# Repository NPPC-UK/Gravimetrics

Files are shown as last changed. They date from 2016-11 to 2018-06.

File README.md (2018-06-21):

# What is a Gravimetrics phenotyping system?

This system is designed to enable the study of mass/weight change over time for a set or sets of plants. Additionally, the automatic watering and drought of plants are handled by this system.

By recording changes in weight at a minute-minute scale, plant behaviours can be accurately described, allowing for sophisticated and informative research to be undertaken.

Here, a full blueprint and implementation compendium for a plant phenotyping system is provided.

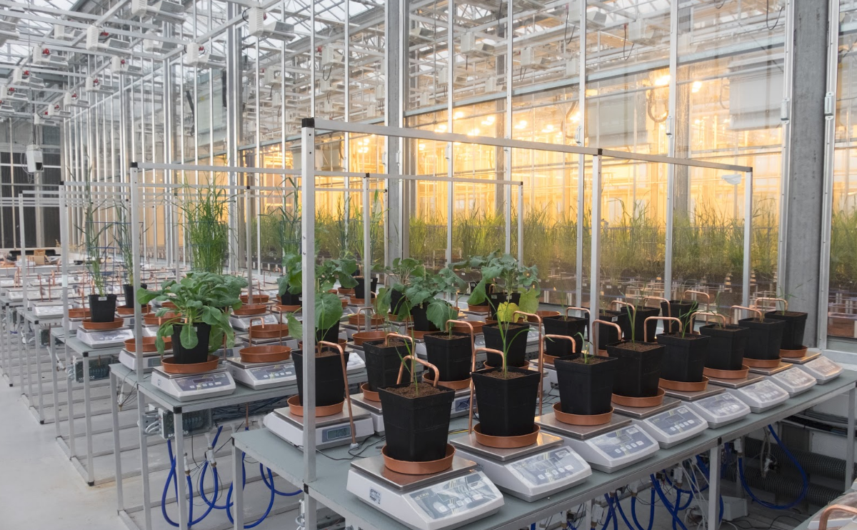
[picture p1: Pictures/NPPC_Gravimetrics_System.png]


# What is provided?

While there exists commercial solutions to gravimetric plant phenotyping, none are provided as open-source solutions.

This project was designed and implemented at the National Plant Phenomics Centre in Aberystwyth, Wales, UK. Built from the ground up using widely available parts, allowing for adaption and scaling.

Designs for physical hardware components used, software for hardware interaction, databases and web interfaces are all provided.

# System Flow Diagram

The basic day-to-day flow is as such:

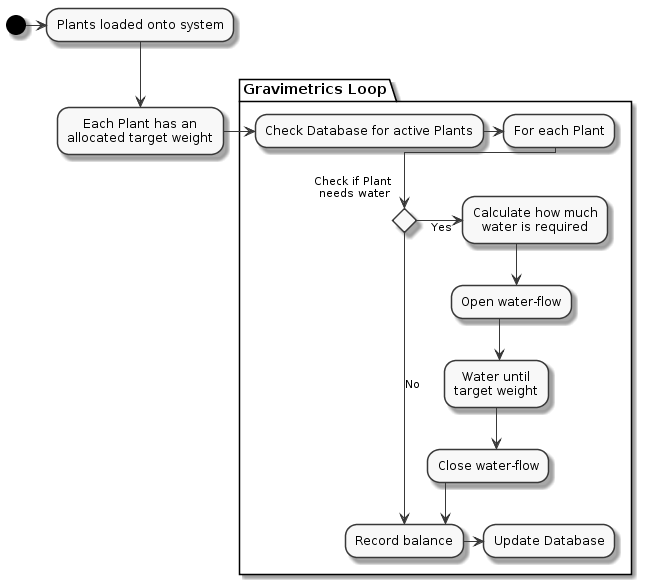
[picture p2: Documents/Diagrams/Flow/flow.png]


Additional interactions, such as updating weights or changing watering times/frequency is performed manually through the web interface.

# Components

Key components provided are:

## Master Controller

To provide a clean and simple interface between hardware and software, a central python script is used to fetch information from the database and pass it to the low-level hardware interactions, it also interprets output and updates the database accordingly.

## Hardware Interaction

A low-level unix C library named "Gravi<sub>Utils</sub>" is used to interact with load-cells (balances) over a serial connection to a Raspberry Pi controller.

In addition to reading balance information for a series of load-cells, the utilities library controls and manages the watering of plants.

## Web Interface

A Flask based web server allows for simple uploading of new plants and experiments onto the system - this is designed for non-technical users to interact with.

Relying heavily on interpreting CSV files and converting them to database queries, the interaction is straight forward.

## System Design Documentation

Everything from electrical wiring diagrams, Raspberry Pi GPIO connections to prototype designs are available in various files.

## Database Configuration

A MySQL database has been used for this project, setup scripts and database schemas are provided that quickly construct and setup all tables and requirements.

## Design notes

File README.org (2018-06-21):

#+TITLE: Gravimetrics - An open source, scalable, plant phenotyping solution
#+AUTHOR: Nathan Hughes, Colin Sauze, Jason Brook, John Doonan
#+OPTIONS: toc:nil

* What is a Gravimetrics phenotyping system?

This system is designed to enable the study of mass/weight change over time for a set or sets of plants. Additionally, the automatic watering and drought of plants are handled by this system.

By recording changes in weight at a minute-minute scale, plant behaviours can be accurately described, allowing for sophisticated and informative research to be undertaken.

Here, a full blueprint and implementation compendium for a plant phenotyping system is provided.



* What is provided?

While there exists commercial solutions to gravimetric plant phenotyping, none are provided as open-source solutions.

This project was designed and implemented at the National Plant Phenomics Centre in Aberystwyth, Wales, UK. Built from the ground up using widely available parts, allowing for adaption and scaling.

Designs for physical hardware components used, software for hardware interaction, databases and web interfaces are all provided.

* System Flow Diagram

The basic day-to-day flow is as such:



Additional interactions, such as updating weights or changing watering times/frequency is performed manually through the web interface.

* Components

Key components provided are:

** Master Controller

To provide a clean and simple interface between hardware and software, a central python script is used to fetch information from the database and pass it to the low-level hardware interactions, it also interprets output and updates the database accordingly.

** Hardware Interaction

A low-level unix C library named "Gravi_Utils" is used to interact with load-cells (balances) over a serial connection to a Raspberry Pi controller.

In addition to reading balance information for a series of load-cells, the utilities library controls and manages the watering of plants.

** Web Interface

A Flask based web server allows for simple uploading of new plants and experiments onto the system - this is designed for non-technical users to interact with.

Relying heavily on interpreting CSV files and converting them to database queries, the interaction is straight forward.

** System Design Documentation

Everything from electrical wiring diagrams, Raspberry Pi GPIO connections to prototype designs are available in various files.

** Database Configuration

A MySQL database has been used for this project, setup scripts and database schemas are provided that quickly construct and setup all tables and requirements.

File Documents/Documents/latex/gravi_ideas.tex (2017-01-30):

% Created 2016-08-02 Tue 10:54
\documentclass[11pt]{article}
\usepackage[utf8]{inputenc}
\usepackage[T1]{fontenc}
\usepackage{fixltx2e}
\usepackage{graphicx}
\usepackage{longtable}
\usepackage{float}
\usepackage{wrapfig}
\usepackage{rotating}
\usepackage[normalem]{ulem}
\usepackage{amsmath}
\usepackage{textcomp}
\usepackage{marvosym}
\usepackage{wasysym}
\usepackage{amssymb}
\usepackage{hyperref}
\tolerance=1000
\author{Nathan}
\date{\today}
\title{gravi\_ideas}
\hypersetup{
  pdfkeywords={},
  pdfsubject={},
  pdfcreator={Emacs 25.1.50.2 (Org mode 8.2.10)}}
\begin{document}

\maketitle
\tableofcontents

\clearpage 

\section{Lifting mechanisms}
\label{sec-1}

One possible solution to our problems could be to introduce a lifting mechanism this would allow us to tare each load cell before a reading, making it 
more likely that we would received a correct reading. 

Any solution which uses a lift would require us to have a dual table system: 

\subsection{Linear Actuator}
\label{sec-1-1}

\href{http://www.instructables.com/id/Electric-Height-Adjustable-Desk/?ALLSTEPS}{Drawing inspiration from this example} we could attempt to make use of the hollow legs in the current
tables by inserting actuators in them. 

Whilst this would make for a nice setup that could be automated, it does become a little more complex 
and does introduce a few areas of concern. However these devices are generally very reliable. 
\begin{figure}[htb]
\centering

\caption{\label{fig:Linear-Actuator}Linear actuators at four corners to lift bench}
\end{figure}

\subsubsection{Alternate design}
\label{sec-1-1-1}

Rather than lifting the plants each time, it might be more prudent to lift the scales themselves rather than the 
plants each time. It would generally be less load on the actuators, however 
\begin{figure}[htb]
\centering

\caption{\label{fig:Linear-Actuator}Linear actuators at four corners to lift bench}
\end{figure}

\subsubsection{Choice of Actuator}
\label{sec-1-1-2}

If we assume that each bench will have up-to 8 load cells on it, each with a max of 10kg each (including itself) 
then we would need a device capable of 80kg force

\begin{center}
\begin{tabular}{rlll}
Option & Price & Potential Lift & Range\\
1 & £89.77 & 28.1N & 48mm\\
2 & £25.55 & 43N & 10mm\\
3 & £174.27 & 500N & 50mm\\
\end{tabular}
\end{center}

I would have assumed that option 2 could have a lot of potential as we really only need a minimum lift 
from the surface of the load cells in order to perform a tare function. 

I've selected option 1 as a mid-priced option and option 3 as a "if we were considering heavier plants." 
\begin{enumerate}
\item Option 1:
\label{sec-1-1-2-1}

\begin{itemize}
\item \url{http://uk.rs-online.com/web/p/electric-linear-actuators/4540990/?origin=PSF_421233|cav}

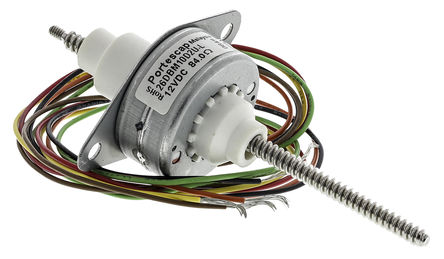
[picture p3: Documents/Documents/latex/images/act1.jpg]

\end{itemize}

\item Option 2:
\label{sec-1-1-2-2}

\begin{itemize}
\item \url{http://uk.rs-online.com/web/p/electric-linear-actuators/4947234/}

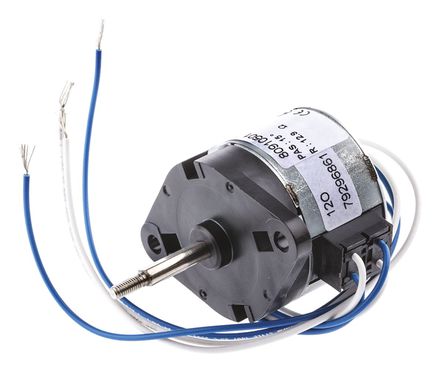
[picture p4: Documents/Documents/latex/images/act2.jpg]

\end{itemize}

\item Option 3:
\label{sec-1-1-2-3}

\begin{itemize}
\item \url{http://uk.rs-online.com/web/p/electric-linear-actuators/7643477/}

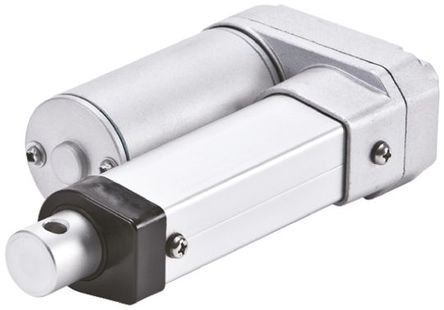
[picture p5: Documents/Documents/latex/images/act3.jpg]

\end{itemize}
\end{enumerate}

\subsection{Scissor Jack}
\label{sec-1-2}

A scissor style jack could be a potential solution as it would probably be the lowest cost (initially) solution, a 
jack could cost us under £15. The downside being that this is a semi-manual solution were we would have to hand wind
the jack up and down for each bench

However it is feasible that a balance could be reliable to +- 2\textasciitilde{}\% for the first 3 days. This could mean we just have to twice a week perform a manual taring. It would save having to 
lift by hand 120 plants. 

Although there are potential improvements which could be made to automate this process with motorized devices. 

\begin{figure}[htb]
\centering

\caption{\label{fig:Scissor-Jack-2}Alternate placement making use of one scissor jack}
\end{figure}

\begin{enumerate}
\item Placement of Jack
\label{sec-1-2-0-1}
Initially I would have thought that this placement shown would be fine for the jack, where it would push from the center of 2 joint benches 
in order to successfully use one lift without any breaks. 

\begin{figure}[htb]
\centering

\caption{\label{fig:Jack-location}Red cross showing where the jack would be}
\end{figure}

\subsubsection{Choice of Scissor jack}
\label{sec-1-2-1}

There are a lot of retailers offering scissor jacks, as an example I have provided a link to \href{https://www.amazon.co.uk/3M-66183c-Tonne-Scissor-Jack/dp/B002NUBHAM}{Amazon} (which is one of the cheaper ones). 
It is a fairly standard item so not a problem to get a hold off. 

\subsubsection{Alternate solution: Two Jack}
\label{sec-1-2-2}
Another possible solution is to use two individual jacks in order to push from either side at the same time to better stable.
\begin{figure}[htb]
\centering

\caption{\label{fig:Scissor-Jack}Scissor Jack example showing load cell and area for plant to be raised}
\end{figure}

\subsubsection{Alternate Jack type: Beam Jack}
\label{sec-1-2-3}

An alternate type of jack that we could use is the \href{http://www.screwfix.com/p/hilka-pro-craft-2-tonne-jacking-beam/21536}{beam jack} which has a much higher load capacity as well as 
a more stable push as it has two points of balance, rather than scissor jack of one. 

\begin{figure}[htb]
\centering
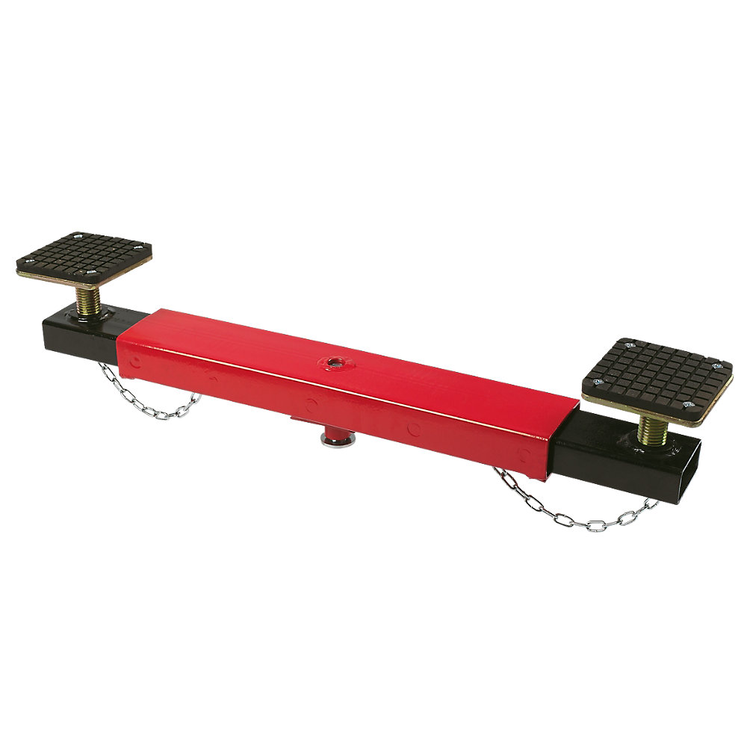
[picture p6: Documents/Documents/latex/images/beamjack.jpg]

\caption{\label{fig:-Beam-Jack}Beam Jack}
\end{figure}

\section{Alternate Loadcell solutions}
\label{sec-2}

From looking at how the results of readings vary depending on load cell and there is no linearity between the environment 
and balance reading at the time. 

Replacing the load cells seems like a sensible path at this stage.  

\subsection{Building our own loadcell}
\label{sec-2-1}

The alternate to trying to get our current load cells to work is an attempt at constructing our own load cells. There are two options 
for this both will most likely costing a lot more than the aforementioned solution of a lifting mechanism. 

\subsubsection{Hanging Basket}
\label{sec-2-1-1}

S-Beam load cells are designed for constant load, they are used often in construction of bridges and buildings where a joint will be under constant strain
and it is important for this to be monitored over time for changes. 

For us to benefit from this we would require a hanging basket to hold plants 
\begin{figure}[htb]
\centering

\caption{\label{fig:Hanging-Basket}Example of a hanging basket}
\end{figure}

\begin{enumerate}
\item Suggested Cell
\label{sec-2-1-1-1}
The omega LCM101 can handle 10kg of force but can come in models supporting up-to 10,000 kg
Price: £222
\begin{figure}[htb]
\centering
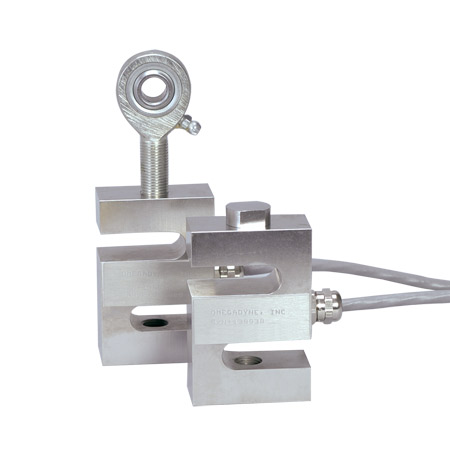
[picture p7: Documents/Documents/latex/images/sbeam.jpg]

\caption{\label{fig:S-Beam}S-Beam load cell}
\end{figure}
\end{enumerate}

\subsubsection{Beam}
\label{sec-2-1-2}
The omega LCM501 cell has very high accuracy and Omega has assured me that this load cell has very little
creep factor and would be suitable for what we want to do. 

Price: £249
\begin{figure}[htb]
\centering
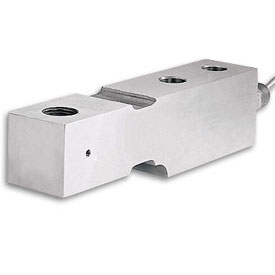
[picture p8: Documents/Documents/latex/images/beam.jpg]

\caption{\label{fig:Beam}Beam load cell}
\end{figure}

\subsubsection{Additional info on constructing loadcells}
\label{sec-2-1-3}

The additional issue with building our own is that we would need to source amplifier boards 
e.g \href{http://www.omega.co.uk/pptst/TXDIN1600S.html}{Expensive one}, or \href{https://www.proto-pic.co.uk/sparkfun-load-cell-amplifier-hx711.html?gclid\%3DCjwKEAjw5vu8BRC8rIGNrqbPuSESJADG8RV0786RXJOCIUPOVZj8QwYWbhOZYXY1rYzwlpp2wl3cfRoCgTTw_wcB}{this cheap one}. 

Moreover we would need to worry about casing and could still face the same creep problem as before, 
without building prototypes we couldn't be sure to their reliability. 

\subsection{Purchase options}
\label{sec-2-2}

\subsubsection{Phenospex}
\label{sec-2-2-1}

\begin{figure}[htb]
\centering
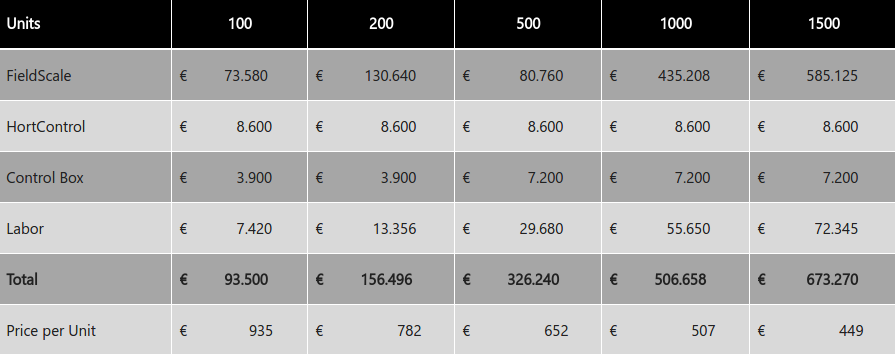
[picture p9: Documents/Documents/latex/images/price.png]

\caption{\label{fig:Phenospex-prices}Phenospex quotes}
\end{figure}

\subsubsection{Mettler Toledo PL6001E}
\label{sec-2-2-2}

Price: £600\textasciitilde{} per balance

The other option are these scales which I have been assured can do dynamic, continuous weighing. 
\href{http://uk.mt.com/dam/P5/labtec/03_Precision_Balances/12_PL-E/03_Documentation/02_Datasheet/DS_PL-E_Precision_EN.pdf}{PDF of this model }

\begin{figure}[htb]
\centering
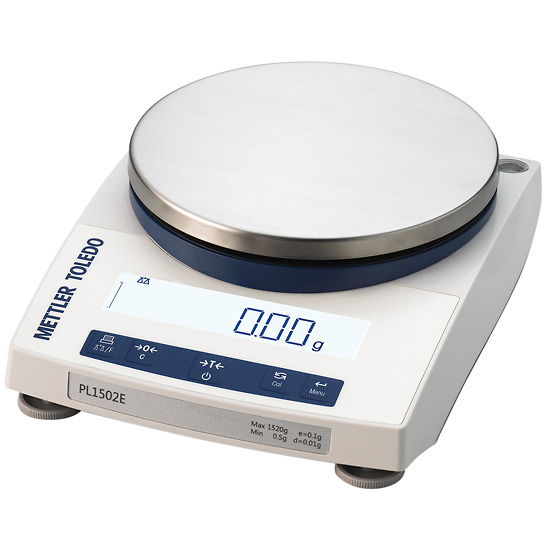
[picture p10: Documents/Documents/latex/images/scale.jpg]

\caption{\label{fig:MT-Scale}Mettler Toledo scale}
\end{figure}
% Emacs 25.1.50.2 (Org mode 8.2.10)
\end{enumerate}
\end{document}

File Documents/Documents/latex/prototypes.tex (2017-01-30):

\documentclass[11pt]{article}
\usepackage{titlesec}
\usepackage{graphicx}
\usepackage{float}
\usepackage{sectsty}
\usepackage[a4paper, total={6in, 9in}]{geometry}
\usepackage[hidelinks]{hyperref}
\usepackage{longtable}
% \subsectionfont{\normalfont\large\itshape\underline}
% \paragraphfont{\normalfont\itshape}
\setlength{\parskip}{1em}

\graphicspath{ {images/} }

\author{Nathan}
\date{\today}
\title{Prototype designs for cost effective continuous weighing systems}

\setcounter{secnumdepth}{4}
\titleformat{\paragraph}
{\normalfont\normalsize\bfseries}{\theparagraph}{1em}{}
\titlespacing*{\paragraph}
{0pt}{3.25ex plus 1ex minus .2ex}{1.5ex plus .2ex}

\begin{document}

\maketitle
\clearpage 
\tableofcontents
\clearpage

%%%%%%%%%%%%%%%%%%%%%%% Intro%%%%%%%%%%%%%%%%%%%%%%%%%%%%%%%%
\section{Introduction}
Compartment 7 in our smart-house aims to be a sophisticated gravimetrics system, where plants can be under controlled
environments, automatically weighed and watered over time.

\par

Typically this would require very precise, expensive and specialist equipment to perform. Our aim is to find a
cost effective way to do this. We will be working off the rough idea that a professional implementation would cost in the
range of \pounds1000 per plant, at current we have space for and aim to facilitate up-to 120 plants at any-one time therefore a
complete system with a cost lower than \textsterling1000 per plant and/or an overall cost less than \textsterling120,000

\par

At current we have the facility to read the weight of each individual plant, water and collect information into a
database. However some issues have been uncovered that make this system unsuitable for scientific experiments.
\subsection{What is the problem with the current solution?}
The main issue that we have encountered when working with the current implementation is that some
of the weighing results that we gathered were seeming off and inconsistent with previous readings
and expectations. Investigation into this led us to believe that the typical load-cell used in a
laboratory scale are ill-suited for continuous weighing.

\par

Load-cells by their nature are very sensitive to changes in their environment in particular temperature.
In a green-house environment this quickly becomes a problem. Through a series of tests we discovered a
potential drift in scale readings of \(\pm10\%\)

\subsection{Why a software approach isn't possible}
TODO
\subsection{How a hardware approach could be the solution}
TODO

%%%%%%%%%%%%%%%%%%%%%%% Solutions%%%%%%%%%%%%%%%%%%%%%%%%%%%%%%
\section{Solutions}
For each of these proposed solutions we work off some assumptions about the weights that we will be working with.
At most we can assume we will not have to handle plants that are over 10kg in weight, and we would take into account that
each scale is around 1kg as well. At current our benches/tables consist of 2$\times$2 smaller benches.
Each of these smaller benches hold 4 plants so we will aim for each section of a bench to hold/lift a minimum of 44kg and for a complete bench to hold/lift a minimum of 176kg. To be safe our prototypes will aim above this where possible within the scope.

\subsection{Linear Actuators}
The use of linear actuators would use electrically powered stepper motors to produce upwards or
downwards movements. 
\subsubsection{Design}
When using linear actuators we have two options, either lift the plants from the balances, or else lift the balances to the
plants. I think both are viable options and that by prototyping both options we can better see which has a more practical
application within the Gravimetrics system. 

\paragraph{Lifting balances}\mbox{}\\
Here we would lift a load-cell (the cylinder) up to a plat above it. This method allows for the loadcells
to be given some time without being stressed with weights on them (which could damage the hardware if left in constant strain). 

\begin{figure}[H]
  \begin{center}
    
    \caption{Lifting scales to the plants using actuators}
  \end{center}
\end{figure}

\paragraph{Lifting plants}\mbox{}\\
Alternately we could attempt to lift the plants themselves. This could be more simple to implement.
Holding the plants above the load cells using the actuators would not necessarily be a strain as
they are perfectly capable of holding at a specific height.

\begin{figure}[H]
  \begin{center}
    
    \caption{Lifting plants using actuators}
  \end{center}
\end{figure}

\subsubsection{Prototype Proposal}
For the prototype of this system we would hope to be able to lift a single bench of 4 plants a minimum of 10mm away from
the load-cells. Too small a movement and we run the risk of a dip in the bench material due to weight. We must also take into account
the possibility of losing track of the current actuator height and so under/over lifting needs to have buffer room which anything less than 10mm
couldn't provide comfortably. 
\paragraph{Parts List}

\begin{center}
  \begin{longtable}{||c |  p{0.25\linewidth}   |c | c | c||} 
    \hline
    Part & Supplier & Part No & Quantity & Price \\ [0.5ex] 
    \hline\hline
    Linear Actuator & RS & 764-3471 & 1 & \pounds176.69 \\ 
    \hline
    Actuator Controller & RS & 918-1372 & 1  & \pounds48.64 \\
    \hline
    Various fittings & RS & X & X &  \pounds15 \\
    \hline
    \hline
    Total & & & & \pounds240.33 \\
    \hline
  \end{longtable}
\end{center}

\paragraph{Estimated Cost} \mbox{}\\
TODO
\subsubsection{Benefits}
TODO
\subsubsection{Possible issues}
TODO
\paragraph{Maintainability}\mbox{}\\
TODO

\subsection{Scissor Jack}
The scissor jack is perhaps one of the simplest mechanisms and would require the least amount of work in order to setup a
brief example. However it would require the user to manually move it initially (However a DC motor could be used in the
future to provide and more automated mechanism). 
\subsubsection{Design}
The design again being simple would require the load-cell to be balanced upon the scissor jack, we then apply a turning
motion to raise the balance to the plants which by taking the weight of the plant pot (cut through the table) we can proceed
to read the weight of the load cells. 

\begin{figure}[H]
  \begin{center}
    
    \caption{Lifting scales to the plants using actuators}
  \end{center}
\end{figure}

\subsubsection{Prototype Proposal}
For this proposed prototype all we require (that is unique to this prototype) is the scissor jack itself. Other materials
such as aluminium for the frame of the holder and lifter is something that we can re-use between prototypes. 
\paragraph{Parts List}\mbox{}\\

\begin{center}
  \begin{longtable}{||c |  p{0.25\linewidth}   |c | c | c||} 
    \hline
    Part & Supplier & Part No & Quantity & Price \\ [0.5ex] 
    \hline\hline
    Scissor Jack & Screwfix & 97595 & 2 & \pounds14.99 \\ 
    \hline
    \hline
    Total & & & & \pounds29.98 \\
    \hline
  \end{longtable}
\end{center}

\paragraph{Estimated Cost}\mbox{}\\
The main cost of this is the scissor jack, in addition to smaller parts that are not important to mention I would suggest
that the price of this setup to be <\pounds30, with the majority being between some aluminium frames and the scissor jack itself. 
\subsubsection{Benefits}

The main benefits of using this type of system are:
\begin{itemize}
  \item Cheap to setup
  \item Room to expand to become automated
  \item Easily maintained
  \item Parts are widely available and manufacturer doesn't matter 
\end{itemize}

\subsubsection{Possible issues}

The foreseeable issues are:  
\begin{itemize}
  \item Not initially automated
  \item Accurately and consistently turning a motor a specific am mount can be  
  
\end{itemize}

\paragraph{Maintainability}
TODO

\subsection{Hanging Basket}
TODO
\subsubsection{Design}

\begin{figure}[H]
  \begin{center}
    
    \caption{Holding the plants in a basket, with an S-Beam load-cell}
  \end{center}
\end{figure}

\subsubsection{Prototype Proposal}
TODO
\paragraph{Parts List}\mbox{}\\

\begin{center}
  \begin{longtable}{||c |  p{0.25\linewidth}   |c | c | c||} 
    \hline
    Part & Supplier & Part No & Quantity & Price \\ [0.5ex] 
    \hline\hline
    Hanging-basket & Homebase & 428809 & 1 & \pounds1.99 \\
    \hline
    S-Beam load-cell & Omega & LCM101 & 1 & \pounds222.00 \\
    \hline
    Amplifier Board & Omega & TXDIN1600S & 1 & \pounds133 \\
    \hline
    \hline
    Total & & & & \pounds356.99 \\
    \hline
  \end{longtable}
\end{center}
\paragraph{Estimated Cost}\mbox{}\\
TODO
\subsubsection{Benefits}
TODO
\subsubsection{Possible issues}
TODO
\paragraph{Maintainability}\mbox{}\\
TODO

\subsection{Alternate Load-Cell}
TODO
\subsubsection{Design}
TODO
\subsubsection{Prototype Proposal}
TODO
\paragraph{Parts List}\mbox{}\\

\begin{center}
    \begin{longtable}{||c | p{0.25\linewidth}   |p{0.25\linewidth} | c | c||} 
      \hline
      Part & Supplier & Part No & Quantity & Price \\ [0.5ex] 
      \hline\hline
      Load-cell & Omega & LCM501  & 1 & \pounds249 \\ 
      \hline
      Amplifier Board & Omega & TXDIN1600S & 1 & N/A \\
      \hline
      \hline
      Total & & & & \pounds249 \\
      \hline
    \end{longtable}
\end{center}

Both prototype load-cell designs can share an amplifier board as the expense is too much to have duplicate components.

\paragraph{Estimated Cost}\mbox{}\\
TODO
\subsubsection{Benefits}
TODO
\subsubsection{Possible issues}
TODO
\paragraph{Maintainability}\mbox{}\\

\subsection{Pneumatic lifting}
Pneumatics could be potential solution in that the majority of the cost is in the initial setup.
Once a suitable air compressor is available, connecting additional valves and cylinders is very economical. 
\subsubsection{Design}
For the design I would be using a setup that is rather simple and borrow a lot from the linear actuators, the main difference
being that this design would incorporate air compressors and pumps in place of electrical powered actuators.

\par

In the diagram given, we can see an air compressor controlled by a servo controller providing a connection to the actuator, these would be controlled by a micro-controller device.

\begin{figure}[H]
  \begin{center}
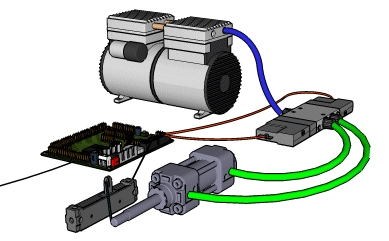
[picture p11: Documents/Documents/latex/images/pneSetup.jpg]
    
    
    \caption{Basic Pneumatic setup using air compressor, servo controller and
      cylinder\cite{dnicky}}
  \end{center}
\end{figure}

\subsubsection{Prototype Proposal}
\paragraph{Parts List}\mbox{}\\

\begin{center}
    \begin{longtable}{||c | p{0.25\linewidth}   |p{0.25\linewidth} | c | c||} 
      \hline
      Part & Supplier & Part No & Quantity & Price \\ [0.5ex] 
      \hline\hline
      Short-stroke cylinder & Festo & ADVC-32-10-I-P-A  & 1 & N/A \\ 
      \hline
      Joining Connectors & RS & 812-156 & 4 & \pounds2.40 \\
      \hline
      Extruded Aluminium & aluminium-profile &  466-7219 & 4 & \pounds17.99\\
      \hline
      Solenoid & RS &  839-3161 & 1 & \pounds78.26\\
      \hline
      Solenoid Connector & RS & 484-010 & 1 & \pounds1.87 \\ [1ex] 
      \hline
      \hline
      Total & & & & \pounds161.69\\
      \hline
    \end{longtable}
\end{center}

\paragraph{Estimated Cost}\mbox{}\\
The estimated costs for this prototype would be around \pounds100.52 although additional cost is not calculated for the creating of an additional hook-up point for the current pump.
\subsubsection{Benefits}
\subsubsection{Possible issues}
\paragraph{Maintainability}\mbox{}\\

%%%%%%%%%General parts required for all prototypes %%%%%%%%%%%%
\subsection{General Parts required} 
\begin{center}
    \begin{longtable}{||c | p{0.25\linewidth}   |p{0.25\linewidth} | c | c||} 
      \hline
      Part & Supplier & Part No & Quantity & Price \\ [0.5ex] 
      \hline\hline
      Extruded Aluminium & aluminium-profile &  466-7219 & 4 & \pounds17.99\\
      \hline
      Stripboard & RS & 100-4328 & 3 & \pounds3.41\\
      \hline
      \hline
      Total & & & & \pounds82.19\\
      \hline
    \end{longtable}
\end{center}

%%%%%%%%%%%%%%%%%%%%%%% Conclusion%%%%%%%%%%%%%%%%%%%%%%%%%%%%
\section{Conclusion}

\subsection{Total Costs for Prototypes}

\begin{center}

  \begin{longtable}{||c|c||}
    \hline
    Prototype & Cost \\ [0.5ex]
    \hline \hline
    Linear Actuators & \pounds240.33\\
    \hline
    Scissor Jack & \pounds29.98\\
    \hline
    Hanging Basket & \pounds356.99 \\
    \hline
    Alternate load-cell &\pounds249 \\
    \hline
    Pneumatics lifting & \pounds161.69 \\ 
    \hline
    General parts & \pounds 82.19
    \hline
    Total & \pounds1120.18 \\
    \hline
  \end{longtable}

\end{center} 

\subsection{Best suited solution}

%%%%%%%%%%%%%%%%%%%%%%% References%%%%%%%%%%%%%%%%%%%%%%%%%%%%
\begin{thebibliography}{9}
  
\bibitem{dnicky} 
  User of indestructibles website, user dnicky,
  \url{http://www.instructables.com/id/Arduino-Pneumatic-Flight-Simulator}
\end{thebibliography}

\end{document}

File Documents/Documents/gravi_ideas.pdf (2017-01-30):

## gravi_ideas

Nathan

August 2, 2016

### Contents

1 Lifting mechanisms | 2
2 Alternate Loadcell solutions | 6

1

### 1 Lifting mechanisms

One possible solution to our problems could be to introduce a lifting mechanism this would allow us to tare each load cell before a reading, making it more likely that we would received a correct reading.
Any solution which uses a lift would require us to have a dual table system:

### 1.1 Linear Actuator

Drawing inspiration from this example (http://www.instructables.com/id/Electric-Height-Adjustable-Desk/?ALLSTEPS) we could attempt to make use of the hollow legs in the current tables by inserting actuators in them.
Whilst this would make for a nice setup that could be automated, it does become a little more complex and does introduce a few areas of concern. However these devices are generally very reliable.

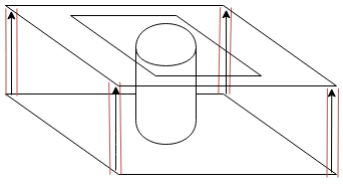
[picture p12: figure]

Figure 1: Linear actuators at four corners to lift bench

### 1.1.1 Alternate design

Rather than lifting the plants each time, it might be more prudent to lift the scales themselves rather than the plants each time. It would generally be less load on the actuators, however

2

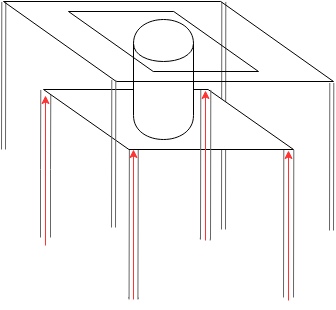
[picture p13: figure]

Figure 2: Linear actuators at four corners to lift bench

### 1.1.2 Choice of Actuator

If we assume that each bench will have up-to 8 load cells on it, each with a max of 10kg each (including itself) then we would need a device capable of 80kg force

Option Price | Potential Lift Range
1 £89.77 | 28.1N | 48mm
2 £25.55 | 43N | 10mm
3 £174.27 500N | 50mm

I would have assumed that option 2 could have a lot of potential as we really only need a minimum lift from the surface of the load cells in order to perform a tare function.
I’ve selected option 1 as a mid-priced option and option 3 as a "if we were considering heavier plants."
1. Option 1:
- http://uk.rs-online.com/web/p/electric-linear-actuators/4540990/?origin=PSF_421233|cav (http://uk.rs-online.com/web/p/electric-linear-actuators/4540990/?origin=PSF_421233|cav)

3

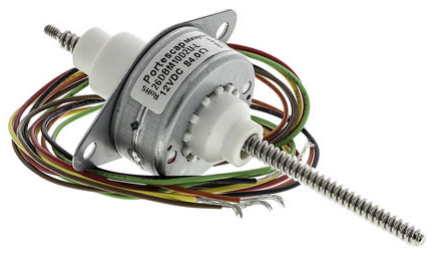
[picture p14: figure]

2. Option 2:
- http://uk.rs-online.com/web/p/electric-linear-actuators/4947234/ (http://uk.rs-online.com/web/p/electric-linear-actuators/4947234/)


3. Option 3:
- http://uk.rs-online.com/web/p/electric-linear-actuators/7643477/ (http://uk.rs-online.com/web/p/electric-linear-actuators/7643477/)

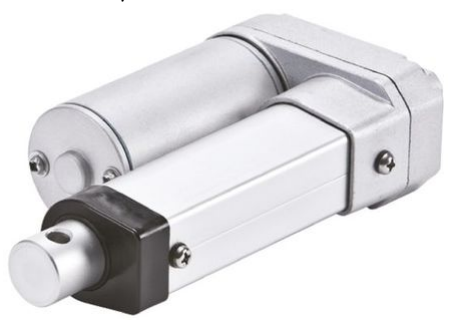
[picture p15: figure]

### 1.2 Scissor Jack

A scissor style jack could be a potential solution as it would probably be the lowest cost (initially) solution, a jack could cost us under £15. The downside being that this is a semi-manual solution were we would have to hand wind the jack up and down for each bench

4

However it is feasible that a balance could be reliable to +- 2~% for the first 3 days. This could mean we just have to twice a week perform a manual taring. It would save having to lift by hand 120 plants.
Although there are potential improvements which could be made to au-tomate this process with motorized devices.

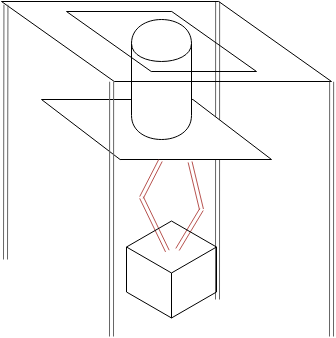
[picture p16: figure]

Figure 3: Alternate placement making use of one scissor jack

1. Placement of Jack Initially I would have thought that this placement shown would be fine for the jack, where it would push from the center of 2 joint benches in order to successfully use one lift without any breaks.

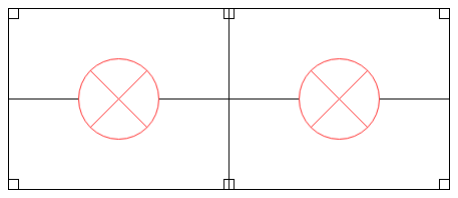
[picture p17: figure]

Figure 4: Red cross showing where the jack would be

### 1.2.1 Choice of Scissor jack

There are a lot of retailers offering scissor jacks, as an example I have provided a link to Amazon (https://www.amazon.co.uk/3M-66183c-Tonne-Scissor-Jack/dp/B002NUBHAM) (which is one of the cheaper ones). It is a fairly standard item so not a problem to get a hold off.

5

### 1.2.2 Alternate solution: Two Jack

Another possible solution is to use two individual jacks in order to push from either side at the same time to better stable.

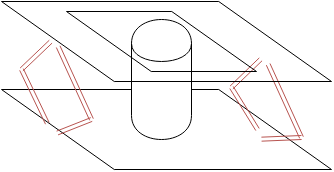
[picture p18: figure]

Figure 5: Scissor Jack example showing load cell and area for plant to be raised

### 1.2.3 Alternate Jack type: Beam Jack

An alternate type of jack that we could use is the beam jack (http://www.screwfix.com/p/hilka-pro-craft-2-tonne-jacking-beam/21536) which has a much higher load capacity as well as a more stable push as it has two points of balance, rather than scissor jack of one.


Figure 6: Beam Jack

### 2 Alternate Loadcell solutions

From looking at how the results of readings vary depending on load cell and there is no linearity between the environment and balance reading

6

at the time.
Replacing the load cells seems like a sensible path at this stage.

### 2.1 Building our own loadcell

The alternate to trying to get our current load cells to work is an attempt at constructing our own load cells. There are two options for this both will most likely costing a lot more than the aforementioned solution of a lifting mechanism.

### 2.1.1 Hanging Basket

S-Beam load cells are designed for constant load, they are used often in construction of bridges and buildings where a joint will be under constant strain and it is important for this to be monitored over time for changes.
For us to benefit from this we would require a hanging basket to hold plants

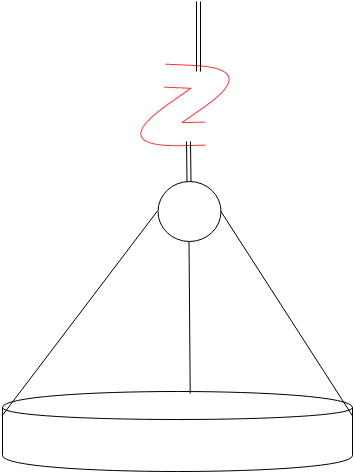
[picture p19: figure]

Figure 7: Example of a hanging basket

(a) Suggested Cell The omega LCM101 can handle 10kg of force but can come in models supporting up-to 10,000 kg Price: £222

7


Figure 8: S-Beam load cell

### 2.1.2 Beam

The omega LCM501 cell has very high accuracy and Omega has assured me that this load cell has very little creep factor and would be suitable for what we want to do.

Price: £249


Figure 9: Beam load cell

### 2.1.3 Additional info on constructing loadcells

The additional issue with building our own is that we would need to source amplifier boards e.g Expensive one, (http://www.omega.co.uk/pptst/TXDIN1600S.html) or this cheap one. (https://www.proto-pic.co.uk/sparkfun-load-cell-amplifier-hx711.html)

8

Moreover we would need to worry about casing and could still face the same creep problem as before, without building prototypes we couldn’t be sure to their reliability.

### 2.2 Purchase options

### 2.2.1 Phenospex


Figure 10: Phenospex quotes

### 2.2.2 Mettler Toledo PL6001E

Price: £600~ per balance

The other option are these scales which I have been assured can do dynamic, continuous weighing. PDF of this model (http://uk.mt.com/dam/P5/labtec/03_Precision_Balances/12_PL-E/03_Documentation/02_Datasheet/DS_PL-E_Precision_EN.pdf)


Figure 11: Mettler Toledo scale

9

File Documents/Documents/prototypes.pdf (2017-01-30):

## Prototype designs for cost effective continuous weighing systems

Nathan

September 7, 2016

1

## Contents

1 Introduction | 4
2 Solutions | 4

2

3 Conclusion | 12

3

## 1 Introduction

Compartment 7 in our smart-house aims to be a sophisticated gravimetrics system, where plants can be under controlled environments, automatically weighed and watered over time.

Typically this would require very precise, expensive and specialist equipment to perform. Our aim is to find a cost effective way to do this. We will be working off the rough idea that a professional implementation would cost in the range of £1000 per plant, at current we have space for and aim to facilitate up-to 120 plants at any-one time therefore a complete system with a cost lower than £1000 per plant and/or an overall cost less than £120,000

At current we have the facility to read the weight of each individual plant, water and collect information into a database. However some issues have been uncovered that make this system unsuitable for scientific experiments.

### 1.1 What is the problem with the current solution?

The main issue that we have encountered when working with the current implementation is that some of the weighing results that we gathered were seeming off and inconsistent with previous readings and expectations. Investigation into this led us to believe that the typical load-cell used in a laboratory scale are ill-suited for continuous weighing.

Load-cells by their nature are very sensitive to changes in their environment in particular temperature. In a green-house environment this quickly becomes a problem. Through a series of tests we discovered a potential drift in scale readings of ±10%

### 1.2 Why a software approach isn’t possible

TODO

### 1.3 How a hardware approach could be the solution

TODO

## 2 Solutions

For each of these proposed solutions we work off some assumptions about the weights that we will be working with. At most we can assume we will not have to handle plants that are over 10kg in weight, and we would take into account that each scale is around 1kg as well. At current our benches/tables consist of 2×2 smaller benches. Each of these smaller benches hold 4 plants so we will aim for each section of a bench to hold/lift a minimum of

4

44kg and for a complete bench to hold/lift a minimum of 176kg. To be safe our prototypes will aim above this where possible within the scope.

### 2.1 Linear Actuators

The use of linear actuators would use electrically powered stepper motors to produce up-wards or downwards movements.

### 2.1.1 Design

When using linear actuators we have two options, either lift the plants from the balances, or else lift the balances to the plants. I think both are viable options and that by proto-typing both options we can better see which has a more practical application within the Gravimetrics system.

### 2.1.1.1 Lifting balances

Here we would lift a load-cell (the cylinder) up to a plat above it. This method allows for the loadcells to be given some time without being stressed with weights on them (which could damage the hardware if left in constant strain).


Figure 1: Lifting scales to the plants using actuators

### 2.1.1.2 Lifting plants

Alternately we could attempt to lift the plants themselves. This could be more simple to implement. Holding the plants above the load cells using the actuators would not necessarily be a strain as they are perfectly capable of holding at a specific height.

5

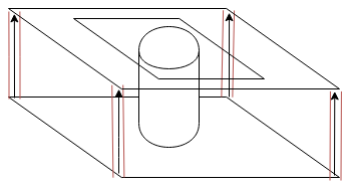
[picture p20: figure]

Figure 2: Lifting plants using actuators

### 2.1.2 Prototype Proposal

For the prototype of this system we would hope to be able to lift a single bench of 4 plants a minimum of 10mm away from the load-cells. Too small a movement and we run the risk of a dip in the bench material due to weight. We must also take into account the possibility of losing track of the current actuator height and so under/over lifting needs to have buffer room which anything less than 10mm couldn’t provide comfortably.

### 2.1.2.1 Parts List

Part | Supplier | Part No | Quantity | Price
Linear Actuator | RS | 764-3471 | 1 | £176.69
Actuator Controller | RS | 918-1372 | 1 | £48.64
Various fittings | RS | X | X | £15
Total | | | | £240.33

### 2.1.2.2 Estimated Cost

TODO

### 2.1.3 Benefits

TODO

### 2.1.4 Possible issues

TODO

6

### 2.1.4.1 Maintainability

TODO

### 2.2 Scissor Jack

The scissor jack is perhaps one of the simplest mechanisms and would require the least amount of work in order to setup a brief example. However it would require the user to manually move it initially (However a DC motor could be used in the future to provide and more automated mechanism).

### 2.2.1 Design

The design again being simple would require the load-cell to be balanced upon the scissor jack, we then apply a turning motion to raise the balance to the plants which by taking the weight of the plant pot (cut through the table) we can proceed to read the weight of the load cells.


Figure 3: Lifting scales to the plants using actuators

### 2.2.2 Prototype Proposal

For this proposed prototype all we require (that is unique to this prototype) is the scissor jack itself. Other materials such as aluminium for the frame of the holder and lifter is something that we can re-use between prototypes.

### 2.2.2.1 Parts List

Part | Supplier | Part No | Quantity | Price

7

Scissor Jack | Screwfix | 97595 | 2 | £14.99
Total | | | | £29.98

### 2.2.2.2 Estimated Cost

The main cost of this is the scissor jack, in addition to smaller parts that are not important to mention I would suggest that the price of this setup to be ¡£30, with the majority being between some aluminium frames and the scissor jack itself.

### 2.2.3 Benefits

The main benefits of using this type of system are:

- Cheap to setup
- Room to expand to become automated
- Easily maintained
- Parts are widely available and manufacturer doesn’t matter

### 2.2.4 Possible issues

The foreseeable issues are:

- Not initially automated
- Accurately and consistently turning a motor a specific am mount can be

### 2.2.4.1 Maintainability TODO

### 2.3 Hanging Basket

TODO

8

### 2.3.1 Design


Figure 4: Holding the plants in a basket, with an S-Beam load-cell

### 2.3.2 Prototype Proposal

TODO

### 2.3.2.1 Parts List

Part | Supplier | Part No | Quantity | Price
Hanging-basket | Homebase | 428809 | 1 | £1.99
S-Beam load-cell | Omega | LCM101 | 1 | £222.00
Amplifier Board | Omega | TXDIN1600S | 1 | £133
Total | | | | £356.99

### 2.3.2.2 Estimated Cost

TODO

### 2.3.3 Benefits

TODO

9

### 2.3.4 Possible issues

TODO

### 2.3.4.1 Maintainability

TODO

### 2.4 Alternate Load-Cell

TODO

### 2.4.1 Design

TODO

### 2.4.2 Prototype Proposal

TODO

### 2.4.2.1 Parts List

Part | Supplier | Part No | Quantity | Price
Load-cell | Omega | LCM501 | 1 | £249
Amplifier Board | Omega | TXDIN1600S | 1 | N/A
Total | | | | £249

Both prototype load-cell designs can share an amplifier board as the expense is too much to have duplicate components.

### 2.4.2.2 Estimated Cost

TODO

10

### 2.4.3 Benefits

TODO

### 2.4.4 Possible issues

TODO

### 2.4.4.1 Maintainability

### 2.5 Pneumatic lifting

Pneumatics could be potential solution in that the majority of the cost is in the initial setup. Once a suitable air compressor is available, connecting additional valves and cylinders is very economical.

### 2.5.1 Design

For the design I would be using a setup that is rather simple and borrow a lot from the linear actuators, the main difference being that this design would incorporate air compressors and pumps in place of electrical powered actuators.

In the diagram given, we can see an air compressor controlled by a servo controller providing a connection to the actuator, these would be controlled by a micro-controller device.

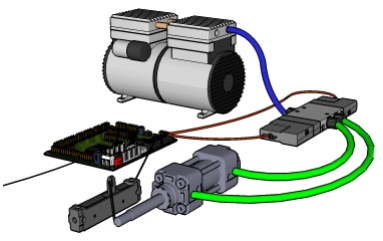
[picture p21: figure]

Figure 5: Basic Pneumatic setup using air compressor, servo controller and cylinder[1]

11

### 2.5.2 Prototype Proposal

### 2.5.2.1 Parts List

Part | Supplier | Part No | Quantity | Price
Short-stroke cylinder | Festo | ADVC-32-10-I-P-A | 1 | N/A
Joining Connectors | RS | 812-156 | 4 | £2.40
Extruded Aluminium | aluminium-profile | 466-7219 | 4 | £17.99
Solenoid | RS | 839-3161 | 1 | £78.26
Solenoid Connector | RS | 484-010 | 1 | £1.87
Total | | | | £161.69

### 2.5.2.2 Estimated Cost

The estimated costs for this prototype would be around £100.52 although additional cost is not calculated for the creating of an additional hook-up point for the current pump.

### 2.5.3 Benefits

### 2.5.4 Possible issues

### 2.5.4.1 Maintainability

### 2.6 General Parts required

Part | Supplier | Part No | Quantity | Price
Extruded Aluminium | aluminium-profile | 466-7219 | 4 | £17.99
Stripboard | RS | 100-4328 | 3 | £3.41
Total | | | | £82.19

12

## 3 Conclusion

### 3.1 Total Costs for Prototypes

Prototype | Cost
Linear Actuators | £240.33
Scissor Jack | £29.98
Hanging Basket | £356.99
Alternate load-cell | £249
Pneumatics lifting | £161.69
General parts | £82.19
Total | £1120.18

### 3.2 Best suited solution

## References

[1] User of indestructibles website, user dnicky, http://www.instructables.com/id/Arduino-Pneumatic-Flight-Simulator (http://www.instructables.com/id/Arduino-Pneumatic-Flight-Simulator)

13

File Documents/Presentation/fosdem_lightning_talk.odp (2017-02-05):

## An open Gravimetric Phenotyping system

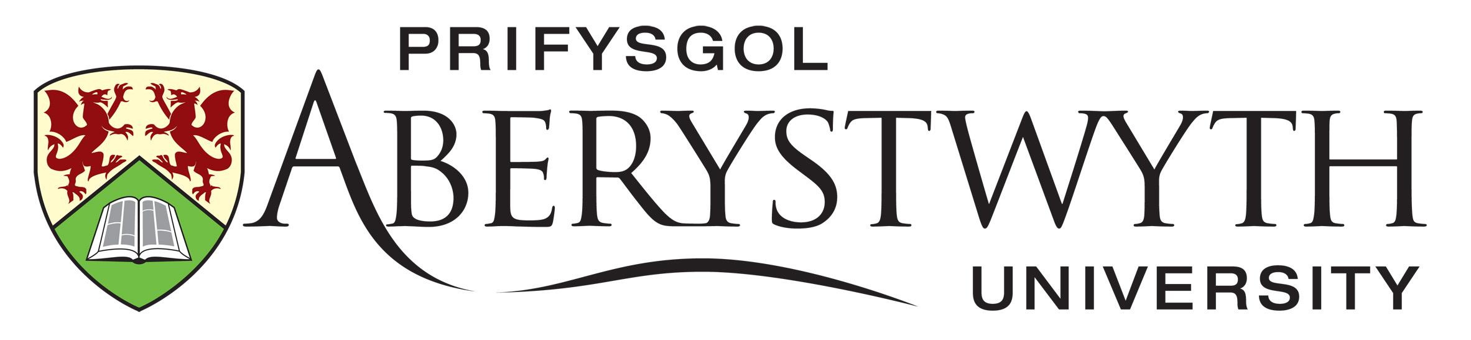
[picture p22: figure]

Finding low-cost solutions to continuous plant monitoring for scientific purposes

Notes: Intro - Hi, I’m Nathan Undergraduate Student at Aberystwyth University Working for a year at the NPPC This talk is about one of the systems I’ve been developing As you can see from the title it’s an open source system That hopefully some people wlll find interesting

## What is it?

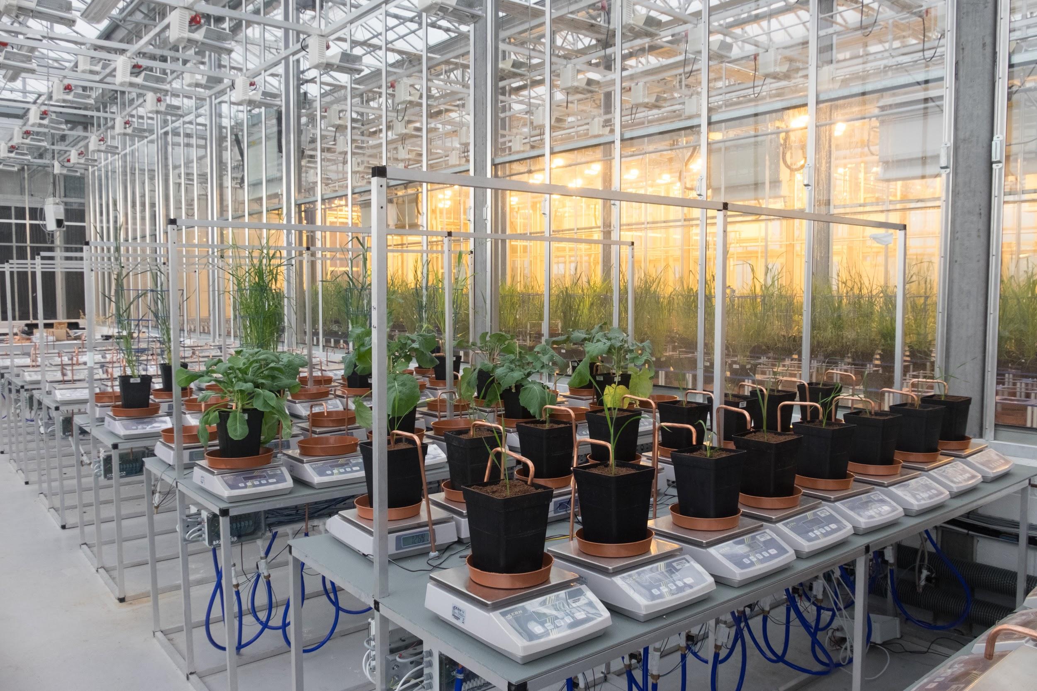
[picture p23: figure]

- Automated monitoring system for plants
- Accurately record biomass growth and water usage
- Watering system
- Has capacity to augment with additional sensory devices

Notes: What is it? An automated system for monitoring plants as they grow and mature Main aim is to accurately measure bio-mass growth and water evaporation Entirely automated watering system Records data directly into a SQL DB Has capactity to augment with any additional sensory equipment you might want E.g. temperature sensors Soil salinity Light level recorders That sort of thing

## Real-Time Information and Monitoring

- Web based interface to give individual plot information
- All written in Python

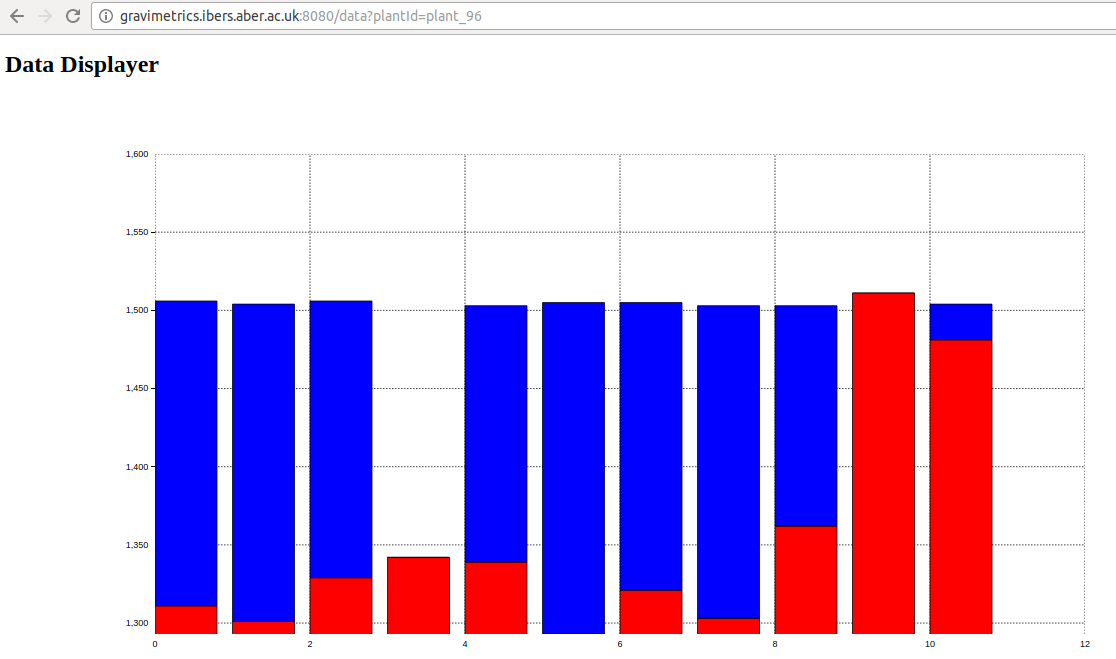
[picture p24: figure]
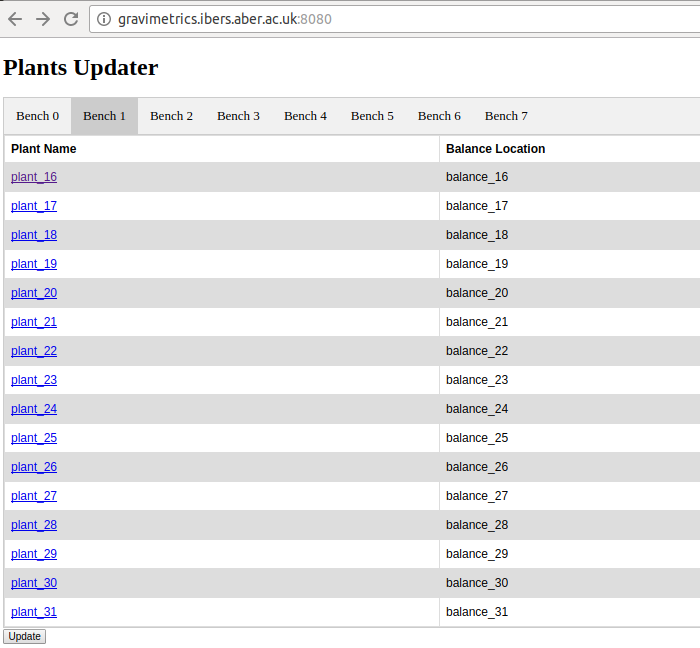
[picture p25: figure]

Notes: The latest part being worked on is the ease of use components Producing a easy to access web portal That in real-time generates useful data Allows management of individual plants by assigning them treatments This side f things is all python And uses matplotlib to generate graphs Also useful to diagnostics E.g. the graph on the right shows water given each morning You can see on the 4th day I accidently turned off the water taps and forgot to put back on!

## What controls it all?

- Raspberry Pi controlled system
- Master Pi running Linux sends commands to nodes that carry out reading/watering tasks
- All core hardware interactions done in C

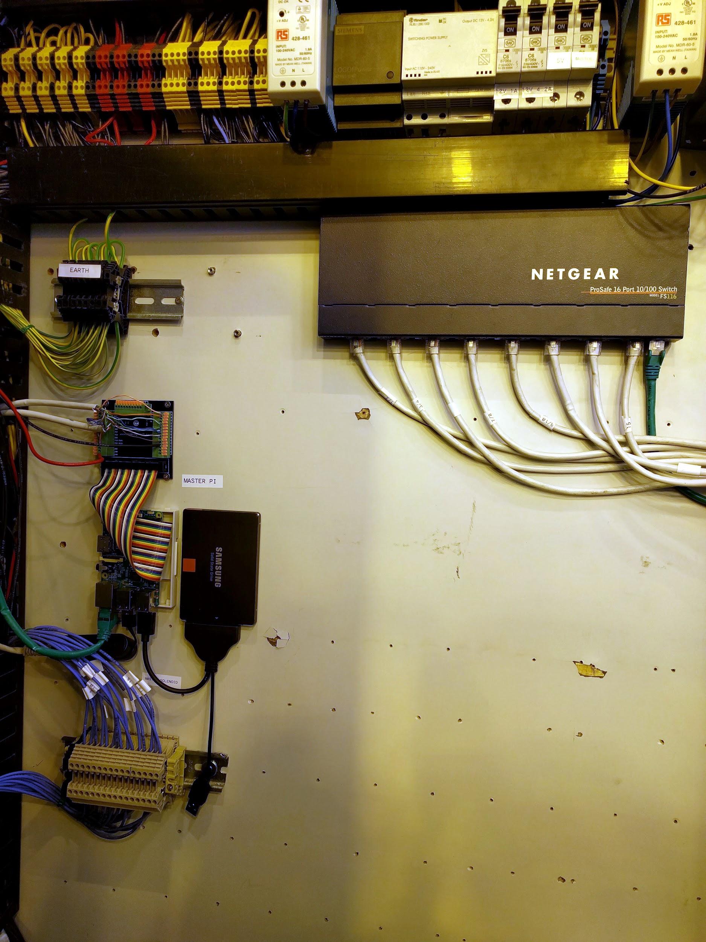
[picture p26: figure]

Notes: All Controlled by a master rasp Pi With 1 node pi assigned to 16 plots All network booted Has a Python script that runs everything Real hardware interaction is done all in pure C

## Why would you want a system like this?

- It’s scalable, high throughput and completely open!
- Allows for creation of data accurate enough for scientific research
- The alternative to the automated system is by using people which takes up:
- Time
- Money
- Humans make mistakes and find it difficult to be consistent in treatments
- Continuous sensor readings delivered in real-time

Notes: It’s very scalable Cheap to get setup with just a few spaces Cheap to expand Cheap to modify Allows for accurate data to be produced, properly formatted and ready to be analysed Saves you lots of manpower Humans make mistakes If you try to water a hundred plants with 1g accuracy you will make mistakes Computers and harware make mistakes too! But we record those mistakes and are *hopefully* consistent in the mistakes Constant 24/7 readings

## Why not just use an off-the-shelf commercial system?

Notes: Why would you not just buy a system There are several companies (I won’t name names) that offer these systems Why would you want to do it yourself?

## Problems with current commercial systems

- Most (all?) of the systems available are completely closed off in regards to their hardware and software
- Inflexible
- We don’t know what experiments are going to require in the future
- We may not even know what kind of data we want to capture
- Expensive initially and to expand
- Almost impossible to maintain without the manufacturer's help

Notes: Professional Companies who design and build these systems tend not to be flexible in giving access to source Explaining how things work under the hood This causes issues for finding and reporting bugs that happen when these systems are in the real world And support is a bad internet connection away… They’re not adaptable: Your needs may change overtime and you can’t afford the downtime or the expense to rebuild the system Maintenance for these huge commercial systems use very hard to source parts, they have single suppliers Takes months to get parts and have to pay far too much!

## Proprietary Black boxes are bad!

- You put plants on the system
- The data recorded is recorded and processed without allowing us to see raw readings
- Some systems are insistent upon storing data we produce on their remote servers
- This creates a lot of issues...

??????

Data

Remote

Server

Plants

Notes: The other problem and the one I’m very concerned with is the data that these systems produce They quickly become black boxes! Plants go in, data gets put into some magical database box, some systems even ship the data off to their private servers that customers don’t have proper access to Data is possibly censored and given back Personally I don’t trust this data too much If you’ve ever worked with hardware sensors you’ll know that your data out isn’t always perfect...

## Our observations on data accuracy

- Through putting together this system ourselves we experienced first-hand how much noise there is in raw-sensor output


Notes: This is my favourite graph to show off, and everyone I know is surely sick of me talking about it These three lines show 3 different weighing stations (load-cells) Each with a constant weight on them Readings taken every minute for 5 days~ There is a lot of noise and it’s things like this that make me not trust proprietary systems I can’t inspect myself. We know we need to find workaroudns for this, but the correction methods we apply will greatly change the output. And makes things a lot harder to replicate for others It’s rather important in science if we can replicate the experiments of others…

## What we have opened up!

- Everything from sketches we have done to parts lists we’ve priced and sourced are completely open
- As is all of the software we have written is completely libre.
- We feel that complete data transparency is the only way to trust what is produced
- Open-source suits this for constantly rolling new techniques into the system


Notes: And that’s why we’ve made this system open! So that there is complete transparency We have open-sourced everything in our system that we’ve built From rough sketches and ideas To parts lists, suppliers and costs

## Thanks!

- FOSDEM lightning talks for having me!
- Aberystwyth University
- National Plant Phenomics Centre
- Contributions from so many people at the University
- BBSRC for funding us.

And Bruce Springsteen for being the backing track whilst all this work was done

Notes: Thanks for letting me give this talk! Thanks for listening And thank you to everyone at Aber U, NPPC and BBSRC for the funding of this!

## Source Code and Contact

All components are freely available:

- Main Repo - https://github.com/NPPC-UK/Gravimetrics
- Controller - https://github.com/NPPC-UK/Gravimetrics/tree/master/Controller
- Web - https://github.com/NPPC-UK/Gravimetrics/tree/master/Website

Contact:

- nah31@aber.ac.uk | nathan1hughes@gmail.com | Twitter: @SirSharpest

Website:

- http://www.plant-phenomics.ac.uk/en/

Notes: Would love it for people to have a look at our code Especially if you fix any bugs I’ve made (surely must be a few) Each component was a submodule at one point, but became too much for what was needed. Would also love if anyone wants to have a chat about anything to drop me an email, tweet or hunt me down before I leave tomorrow!

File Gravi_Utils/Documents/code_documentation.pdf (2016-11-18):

## Gravi_Utils

1.0

### Generated by Doxygen 1.8.11

# Contents

1 File Index | 1
2 File Documentation | 3
2.1.2.5 | water_to_weight(char ∗balance_port_id, char ∗water_port_id, int target_weight) . | 5
Index | 7

## Chapter 1

# File Index

### 1.1 File List

Here is a list of all documented files with brief descriptions:

src/main.c

### 2 File Index

Generated by Doxygen

## Chapter 2

# File Documentation

### 2.1 src/main.c File Reference

Program to interact with scales and solenoids.

#include <stdio.h>

#include <stdlib.h>

#include <fcntl.h>

#include <termios.h>

#include <unistd.h>

#include <string.h>

#include <time.h>

Include dependency graph for main.c:

src/main.c

stdio.h | stdlib.h | fcntl.h | termios.h | unistd.h | string.h | time.h

Macros

- #define WATERTIMEOUT 100

Functions
- int get_balance (char ∗balance_port_id)

Gets the balance of a particular port.
- int water_to_weight (char ∗balance_port_id, char ∗water_port_id, int target_weight)

Waters to the target weight.
- int interact_with_port (char ∗port_id, char BW, char off_on)

Reads/Sets the value of either a water solenoid or a balance.
- void deblank (char ∗input)

Function to remove bad output from a string.
- int main (int argc, char ∗argv[ ])

Main entry point for the program.

### 4 File Documentation

### 2.1.1 Detailed Description

Program to interact with scales and solenoids.

Author
Nathan Hughes

Date
25/8/2016 This program uses C to interact with the hardware in gravimetrics, using standard C commands that will compile on most systems, although aimed primarily for the Raspberry Pi

See also

https://support.plant-phenomics.ac.uk:8081/nah31/Gravi_Utils/

Bug No known issues

### 2.1.2 Function Documentation

### 2.1.2.1 void deblank ( char ∗ input )

Function to remove bad output from a string.

String given to this function should be just numbers, this function ensures that no garbage characters pollute the output of the scales

Parameters
input char array pointer that needs cleaned up

### 2.1.2.2 int get_balance ( char ∗ balance_port_id )

Gets the balance of a particular port.

Parameters

Balance_port←-
_id

the address of the port to examine

Returns
The weight in grams

Generated by Doxygen

2.1 src/main.c File Reference | 5

### 2.1.2.3 int interact_with_port ( char ∗ port_id, char BW, char off_on )

Reads/Sets the value of either a water solenoid or a balance.

Making use of the params given it decides what it should do to a port address given this function will either apply a watering action or a weight reading action either way it returns a value which indicates the weight/exit code of its process

Parameters

port←-_id | the address of the port file
BW | an indication of whether to water or read balance
off_on | indication to write a high or low to the port (used for watering solenoids)

Returns
Either the exit code, or the value of a read balance

### 2.1.2.4 int main ( int argc, char ∗ argv[ ] )

Main entry point for the program.

Takes in a variable number of arguments that can be seen with the "help" command

Parameters
argc | the number of arguments given
argv | the strings passed as arguments details can be found by running Gravi_Utils help

Returns
exit code

2.1.2.5 int water_to_weight ( char ∗ balance_port_id, char ∗ water_port_id, int target_weight )

Waters to the target weight.

This function waters a specific plant pot to the target weight given

Parameters

balance_port←-_id

water_port_id
target_weight

Generated by Doxygen

### 6 File Documentation

Generated by Doxygen

# Index

deblank
main.c, 4

get_balance
main.c, 4

interact_with_port
main.c, 4

main
main.c, 5
main.c
deblank, 4
get_balance, 4
interact_with_port, 4
main, 5
water_to_weight, 5

src/main.c, 3

water_to_weight
main.c, 5

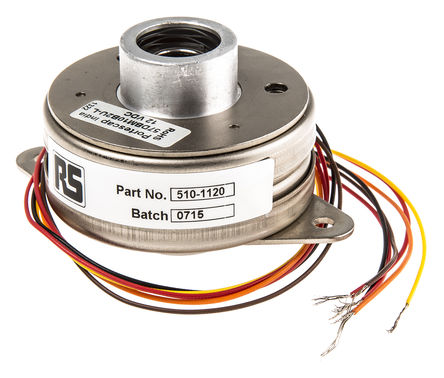
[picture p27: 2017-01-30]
Documents/Documents/latex/images/act4.jpg

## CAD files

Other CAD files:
Documents/Diagrams/freeCAD /Lifting_Frame.fcstd

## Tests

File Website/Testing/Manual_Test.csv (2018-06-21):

TEST | 2018-5-5 | 2018-6-6
W666-0152166 | 1596 | 1
W666-0351166 | 1596 | 2
W666-0451166 | 1376 | 3
W666-0252166 | 1596 | 4
W666-0153166 | 1596 | 5
W666-0353166 | 1596 | 6
W666-0553166 | 1376 | 7
W666-0352166 | 1596 | 8
W666-0453166 | 1376 | 9
W666-0151166 | 1596 | 10
W666-0452166 | 1376 | 11
W666-0251166 | 1596 | 12
W666-0552166 | 1376 | 13
W666-0253166 | 1596 | 14
W666-0666666 | 1376 | 15
W666-0451266 | 1376 | 16
W666-0553266 | 1376 | 17
W666-0153266 | 1596 | 18
W666-0252266 | 1596 | 19
W666-0351266 | 1596 | 20
W666-0453266 | 1376 | 21
W666-0552266 | 1376 | 22
W666-0251266 | 1596 | 23
W666-0152266 | 1596 | 24
W666-0352266 | 1596 | 25
W666-0452266 | 1376 | 26
W666-0151266 | 1596 | 27
W666-0253266 | 1596 | 28
W666-0551266 | 1376 | 29
W666-0353266 | 1596 | 30
W666-0253366 | 1596 | 31
W666-0151366 | 1596 | 32
W666-0451366 | 1376 | 33
W666-0351366 | 1596 | 34
W666-0452366 | 1376 | 35
W666-0551366 | 1376 | 36
W666-0553366 | 1376 | 37
W666-0453366 | 1376 | 38
W666-0252366 | 1596 | 39
W666-0352366 | 1596 | 40
W666-0251366 | 1596 | 41
W666-0552366 | 1376 | 42
W666-0353366 | 1596 | 43
W666-0153366 | 1596 | 44
W666-0152366 | 1596 | 45
W666-0351466 | 1596 | 46
W666-0252466 | 1596 | 47
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

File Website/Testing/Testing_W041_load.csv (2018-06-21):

TEST | 2017-12-18 | 2018-03-26
W041-01521 | 1590 | 1
W041-03511 | 1590 | 2
W041-04511 | 1374 | 3
W041-02521 | 1590 | 4
W041-01531 | 1590 | 5
W041-03531 | 1590 | 6
W041-05531 | 1374 | 7
W041-03521 | 1590 | 8
W041-04531 | 1374 | 9
W041-01511 | 1590 | 10
W041-04521 | 1374 | 11
W041-02511 | 1590 | 12
W041-05521 | 1374 | 13
W041-02531 | 1590 | 14
W041-06666 | 1374 | 15
W041-04512 | 1374 | 16
W041-05532 | 1374 | 17
W041-01532 | 1590 | 18
W041-02522 | 1590 | 19
W041-03512 | 1590 | 20
W041-04532 | 1374 | 21
W041-05522 | 1374 | 22
W041-02512 | 1590 | 23
W041-01522 | 1590 | 24
W041-03522 | 1590 | 25
W041-04522 | 1374 | 26
W041-01512 | 1590 | 27
W041-02532 | 1590 | 28
W041-05512 | 1374 | 29
W041-03532 | 1590 | 30
W041-02533 | 1590 | 31
W041-01513 | 1590 | 32
W041-04513 | 1374 | 33
W041-03513 | 1590 | 34
W041-04523 | 1374 | 35
W041-05513 | 1374 | 36
W041-05533 | 1374 | 37
W041-04533 | 1374 | 38
W041-02523 | 1590 | 39
W041-03523 | 1590 | 40
W041-02513 | 1590 | 41
W041-05523 | 1374 | 42
W041-03533 | 1590 | 43
W041-01533 | 1590 | 44
W041-01523 | 1590 | 45
W041-03514 | 1590 | 46
W041-02524 | 1590 | 47
W041-04517 | 1374 | 48
W041-05526 | 1374 | 49
W041-05534 | 1374 | 50
W041-04525 | 1374 | 51
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

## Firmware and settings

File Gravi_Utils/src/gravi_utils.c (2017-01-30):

/**
 * @file main.c
 * @author Nathan Hughes
 * @date 25/8/2016
 * @brief Program to interact with scales and solenoids
 *
 * This program uses C to interact with the hardware in 
 * gravimetrics, using standard C commands that will compile 
 * on most systems, although aimed primarily for the Raspberry Pi
 *
 * @see https://support.plant-phenomics.ac.uk:8081/nah31/Gravi_Utils/
 * @bug No known issues 
 */
#include "gravi_utils.h"

/**
 * @brief Main entry point for the program
 *
 * Takes in a variable number of arguments that can be seen with the "help" command 
 *
 * @param argc the number of arguments given 
 * @param argv the strings passed as arguments details can be found by running Gravi_Utils help
 * @return exit code 
 *
 */
int main(int argc, char *argv[]) {
  
  if(unlikely(argc < 2)) {
    fprintf(stderr, "Not enough arguments, please state either balance or water with other required information\n");
    return 0;
  }
  else if(argc >= 2 && argc < 5){
    if(!strcmp(argv[1], "help")){
      
      printf("The usage of this program is as follows: "
	     "\nArg 1 can be either \'balance\' or else \'water\' "
	     "\nArg 2 is the balance port address "
	     "\nArgs 3 is used only if watering and is the GPIO address"
	     "\nArg 4 is also only used for watering and is the target weight as an integer value\n" );
      return 0;    
    }
    if(!strcmp(argv[1], "balance")){
      
      /*
       * This is the output to stdout
       */
      printf("%d\n",get_balance(argv[2]));
      exit(EXIT_SUCCESS);
    }

    else if (!strcmp(argv[1], "master")){
	activate_master_solenoid(argv[2], argv[3][0]);
	exit(EXIT_SUCCESS);
      }
    else if (!strcmp(argv[1], "lifter")){
      lift(argv[2], argv[3][0]);
    }
    else if (!strcmp(argv[1], "tare")){
      tare_balance(argv[2]);
    }
    else if (!strcmp(argv[1], "test_gpio")){
      if(interact_with_port(argv[2], 'W', argv[3][0])){
	printf("Sucessfully applied action %c on: %s",  argv[3][0], argv[2]);
	exit(EXIT_SUCCESS);
      }else{
	fprintf(stderr, "Error running the testing script!");
	exit(EXIT_FAILURE);
      }
      
    }
    
    else {
      fprintf(stderr, "Need additional information, contact system administrator\n");
      exit(EXIT_FAILURE);
    }
  }
  
  if (argc == 5 && !strcmp(argv[1], "water")){
    
    /*
     * This is the actual magic being called and printed to the stdin
     */
    printf("%d\n", water_to_weight(argv[2], argv[3], atoi(argv[4])));
    
    exit(EXIT_SUCCESS); 
  }
  else{
    fprintf(stderr, "Something went wrong with the watering\n");
    exit(EXIT_FAILURE);
  }
  return 0; // I can't imagine a condition where this is actually triggered! 
}


/**
 *
 * Function implementations 
 *
 */
int get_balance(char* balance_port_id){
  return interact_with_port(balance_port_id, 'B', 0);
}

int water_to_weight(char* balance_PortID, char* water_port_id, int target_weight){

  int current = get_balance(balance_PortID);
  
  if(current < target_weight){

    /*
     * Start some clocking information
     */
    time_t elapsed = 0, start =time(NULL);
    int tries = 0;
    
    while (interact_with_port(water_port_id, 'W', '1') < 0 && tries < PORTATTEMPTS) // turn water on
      tries++; 

    int initial = get_balance(balance_PortID);
    
    while(current < target_weight && elapsed < WATERTIMEOUT ){
      //wait for watering to be complete
      current = get_balance(balance_PortID);
      elapsed = (time(NULL) - start);

      // if after 10seconds no water appears then something has gone wrong
      if (current == initial && elapsed > WATERCHANGETIMEOUT)
	break;
    }
    
    tries = 0; 
    while (unlikely(interact_with_port(water_port_id, 'W', '0') <  0) && tries < PORTATTEMPTS)
      fprintf(stderr, "Error turning off water\n"); // turn water off
  }
  //wait here as it would increase accuracy of the watering update if we let water settle
  sleep(5);
  return get_balance(balance_PortID);
}


int interact_with_port(char* port_id, char BWLT, char off_on){

  /*
   * Just to clarify: BW, B will refer to balance whilst W refers to watering, and L the lifter 
   */
  speed_t baud = B9600; // baud rate
  int fd = open(port_id, (BWLT == 'B' || BWLT == 'L' || BWLT == 'T') ? O_RDWR : O_WRONLY); //Open the port with the correct RW settings

  struct termios settings; // structure for the settings that will be used for the port 
  tcgetattr(fd, &settings);
  
  cfsetospeed(&settings, baud); // baud rate 
  settings.c_cflag &= ~PARENB; // no parity 
  settings.c_cflag &= ~CSTOPB; // 1 stop bit 
  settings.c_cflag &= ~CSIZE; // Specify the size of   
  settings.c_cflag |= CS8 | CLOCAL; // 8 bits 
  settings.c_lflag = ICANON; // canonical mode 
  settings.c_oflag &= ~OPOST; // raw output 
  tcsetattr(fd, TCSANOW, &settings); // apply the settings 
  tcflush(fd, TCOFLUSH); // Discard useless info 
  fcntl(fd, F_SETFL, 0); // apply file control operations 

  // Initialise file descriptor sets
  fd_set read_fds, write_fds, except_fds;
  FD_ZERO(&read_fds);
  FD_ZERO(&write_fds);
  FD_ZERO(&except_fds);
  FD_SET(fd, &read_fds);

  // Set timeout to 3.0 seconds
  struct timeval timeout;
  timeout.tv_sec = PORTTIMEOUT; // Read timeout defined in header, any more than this and something has went wrong
  timeout.tv_usec = PORTTIMEOUT;
  
  int w = 0;
  if(BWLT == 'W'){
    w = (int)  write(fd, &off_on, 1); 
  }
  else if (BWLT == 'L'){
    w = (int) write(fd, (off_on) ? "d": "l" , 1); // if off == True then drop else lower 
  }
  else if (BWLT == 'T'){
    w = (int) write(fd, "t", 1); // send tare signal 
  }
  else{
    w = (int) write(fd, "w", 1); // writes to the port a w or a 1/0 depending on function 
  }
  
  //If there's an error in writing to the scales then tell us!
  if(unlikely(w < 0) && BWLT != 'L'){
    fprintf(stderr, "Error writting to device: %s\n", port_id);
    return -1; 
  }

  //If we flip switch to water then return as it's worked
  if(BWLT == 'W') return w;
  else if (BWLT == 'L') return w; 

  
  // Wait for input to become ready or until the time out; the first parameter is
  // 1 more than the largest file descriptor in any of the sets
  if (likely(select(fd + 1, &read_fds, &write_fds, &except_fds, &timeout) == 1)) {
    
    //This buffer holds the data from the serial port
    char buffer[BUFFERSIZE]; //Could reduce this to around 18 in length but better to have more buffering room

    // fd is ready for reading
    uint8_t n = (uint8_t) read(fd, buffer, sizeof(buffer));  //Reads the length of the serial data

    buffer[n] = 0;
    
    if(deblank(buffer)) fprintf(stderr, "Error getting data from scales") ; // remove all unhappy characters from the input

    close(fd); // close the connection

    return atoi(buffer); // convert the result to a number and cast to be short
  }
  else
    fprintf(stderr, "Timeout error\n");
  return 0; // timeout or error
}

int activate_master_solenoid(char* port_id, char off_on){
  return  interact_with_port(port_id, 'W', off_on);
}

int deblank(char* input){
  
  char isNumerical = 0;

  for(int i = 0, j = 0; i < (int)strlen(input); i++, j++){

    /* This additional check looks for numbers within the given string
     * if no numbers are present we will return 0 indicating a failure 
     * in finding useful data. 
     */ 
    if (isNumerical != 0 && isdigit(input[i])) isNumerical = 1;  
    
    if(input[i] >= '0' && input[i] <= '9'){
      input[j] = input[i];
    } 
    else{
      j--;
    }
  }
  return isNumerical; 
}

int lift(char* lifter_address, char lift_drop){

  interact_with_port(lifter_address, 'L', (lift_drop == 'l') ? 0 : 1); 
  
  return 0; 
}

int tare_balance(char* balance_address){
  interact_with_port(balance_address, 'T', 0);
  return 0; 
}

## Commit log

2017-01-30 Fixed Some naming and few new documents
    [Lifting_Frame.fcstd]
2018-06-21 Updated the website to Flask
    [Manual_Test.csv, Testing_W041_load.csv]
